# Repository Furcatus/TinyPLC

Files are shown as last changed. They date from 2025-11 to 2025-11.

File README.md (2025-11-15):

# TinyPLC

NOTE: This project is under construction. Do not expect everything to work just yet.

## What is it?
This project provides a small and easy-to-use open-source PLC (programmable logic controller) hardware / software platform intended for small automation and control tasks, built around a Raspberry Pi Pico 2W.

## Who is it for?
TinyPLC aims towards hobbyist developers and electrical engineers who want to easily automate stuff in the physical world with Python, but have been limited due to the lack of peripheral hardware connected to their microcontrollers, until now!

### Hardware features:
- 5V supply voltage
- 4 isolated digital inputs (5V to 24V, isolated external 5V supply through DC/DC converter)
- 4 relay outputs (contact: NO, up to 230V, 10A)
- SPI interface
- I²C interface
- 6 GPIOs (3,3V)
- custom 3D printable enclosure

### Software features:
- controller programmed in MicroPython
- slim PLC framework with user-defined initialization and loop function
- open-source
- possibility to use the WiFi/Bluetooth capabilities of the used Rasperry Pi Pico 2W board to build your own wireless controller

## License and Disclaimer
This project is released under the MIT license. Feel free to use it for your projects, as long as you know what you are doing when dealing with electrics/electronics. I am not liable to any harm you are causing to yourself, others or someone's property when using the provided files. Do not use TinyPLC with dangerous voltages or for safety-critical applications and follow the regulations and laws applicable in your location!

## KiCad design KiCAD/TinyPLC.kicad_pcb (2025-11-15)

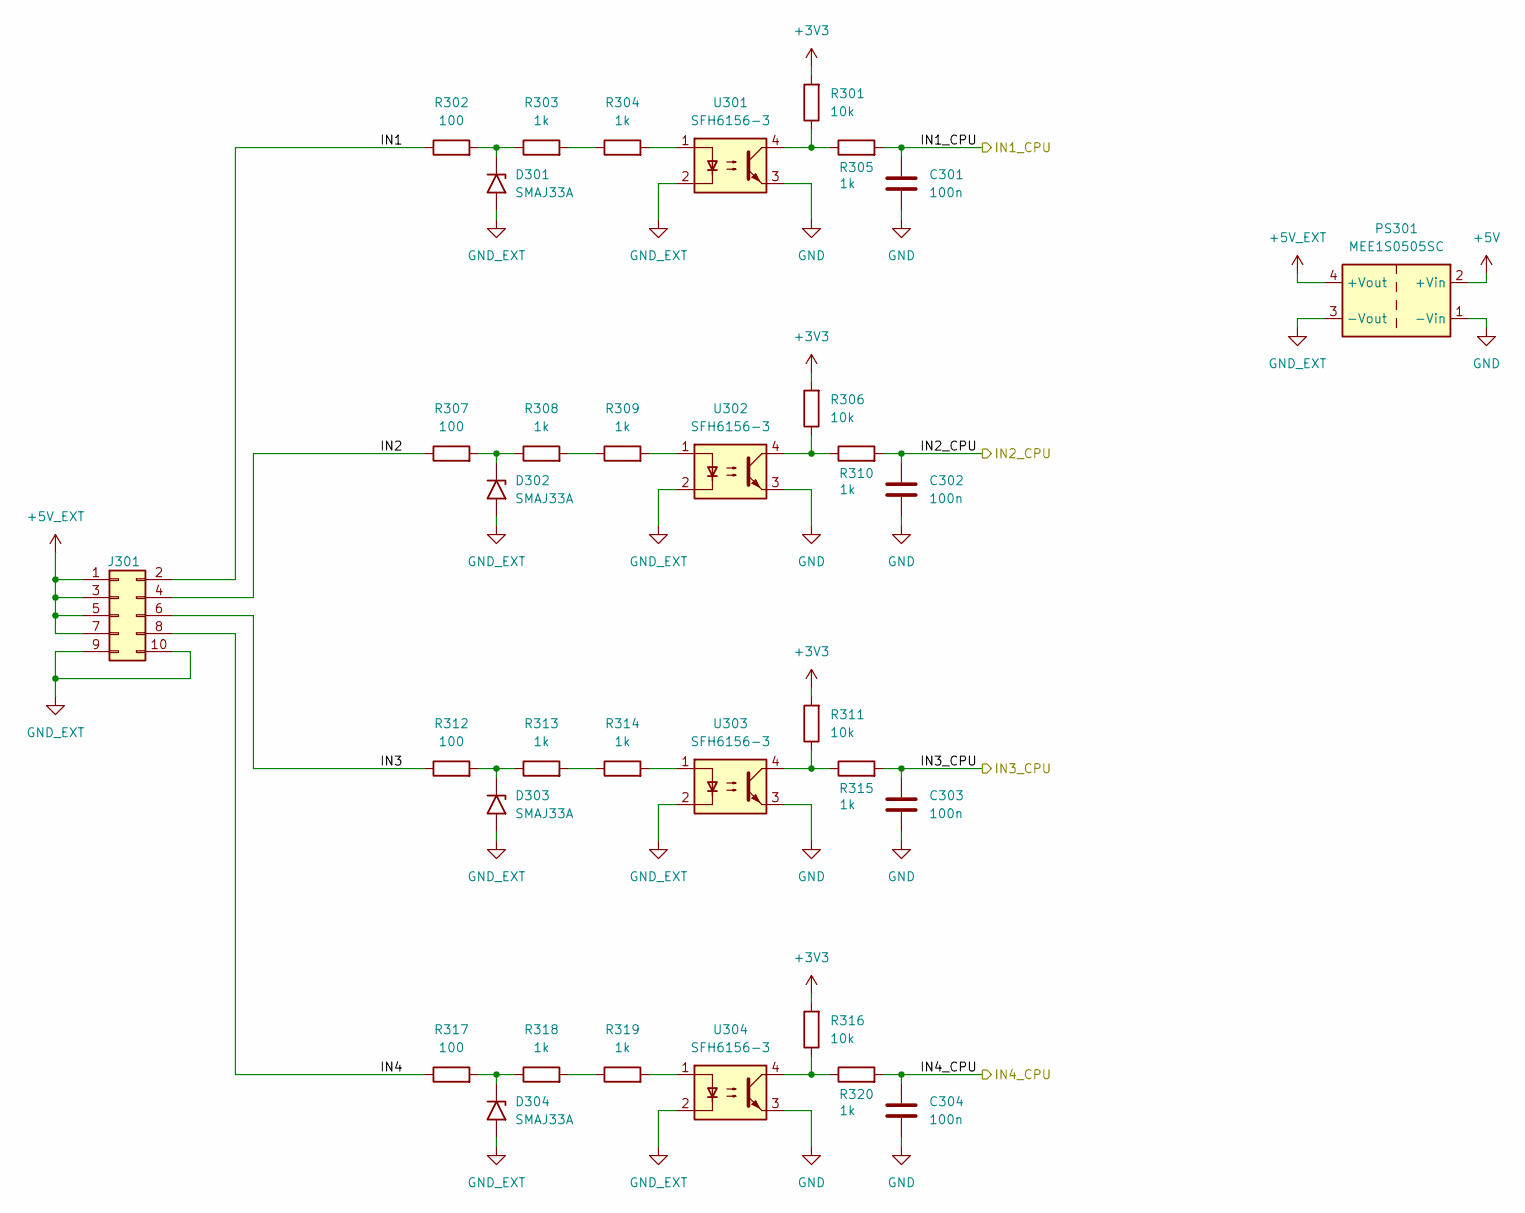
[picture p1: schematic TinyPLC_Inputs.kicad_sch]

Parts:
C301, C302, C303, C304: 100n; C_0603_1608Metric_Pad1.08x0.95mm_HandSolder
D301, D302, D303, D304: SMAJ33A; D_SMA
J301: S2L 3.50/10/180G 3.5SN OR BX; Weidmüller_S2L_2x05_3.50mm
PS301: MEE1S0505SC; Converter_DCDC_Murata_MEE1SxxxxSC_THT
R301, R306, R311, R316: 10k; R_0603_1608Metric_Pad0.98x0.95mm_HandSolder
R302, R307, R312, R317: 100; R_MiniMELF_MMA-0204
R303, R304, R308, R309, R313, R314, R318, R319: 1k; R_1206_3216Metric_Pad1.30x1.75mm_HandSolder
R305, R310, R315, R320: 1k; R_0603_1608Metric_Pad0.98x0.95mm_HandSolder
U301, U302, U303, U304: SFH6156-3; DIP-4_W7.62mm_SMDSocket_SmallPads

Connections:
+3V3: R301.2, R306.2, R311.2, R316.2; also elsewhere on the board
+5V: PS301.2 (+Vin); also elsewhere on the board
+5V_EXT: J301.1, J301.3, J301.5, J301.7, PS301.4 (+Vout)
/Controller/IN1_CPU: C301.1, R305.2; also elsewhere on the board
/Controller/IN2_CPU: C302.1, R310.2; also elsewhere on the board
/Controller/IN3_CPU: C303.1, R315.2; also elsewhere on the board
/Controller/IN4_CPU: C304.1, R320.2; also elsewhere on the board
/Inputs/IN1: J301.2, R302.1
/Inputs/IN2: J301.4, R307.1
/Inputs/IN3: J301.6, R312.1
/Inputs/IN4: J301.8, R317.1
GND: C301.2, C302.2, C303.2, C304.2, PS301.1 (-Vin), U301.3, U302.3, U303.3, U304.3; also elsewhere on the board
GND_EXT: D301.2 (A2), D302.2 (A2), D303.2 (A2), D304.2 (A2), J301.9, J301.10, PS301.3 (-Vout), U301.2, U302.2, U303.2, U304.2
unnamed: D301.1 (A1), R302.2, R303.1
unnamed: D302.1 (A1), R307.2, R308.1
unnamed: D303.1 (A1), R312.2, R313.1
unnamed: D304.1 (A1), R317.2, R318.1
unnamed: R301.1, R305.1, U301.4
unnamed: R303.2, R304.1
unnamed: R304.2, U301.1
unnamed: R306.1, R310.1, U302.4
unnamed: R308.2, R309.1
unnamed: R309.2, U302.1
unnamed: R311.1, R315.1, U303.4
unnamed: R313.2, R314.1
unnamed: R314.2, U303.1
unnamed: R316.1, R320.1, U304.4
unnamed: R318.2, R319.1
unnamed: R319.2, U304.1

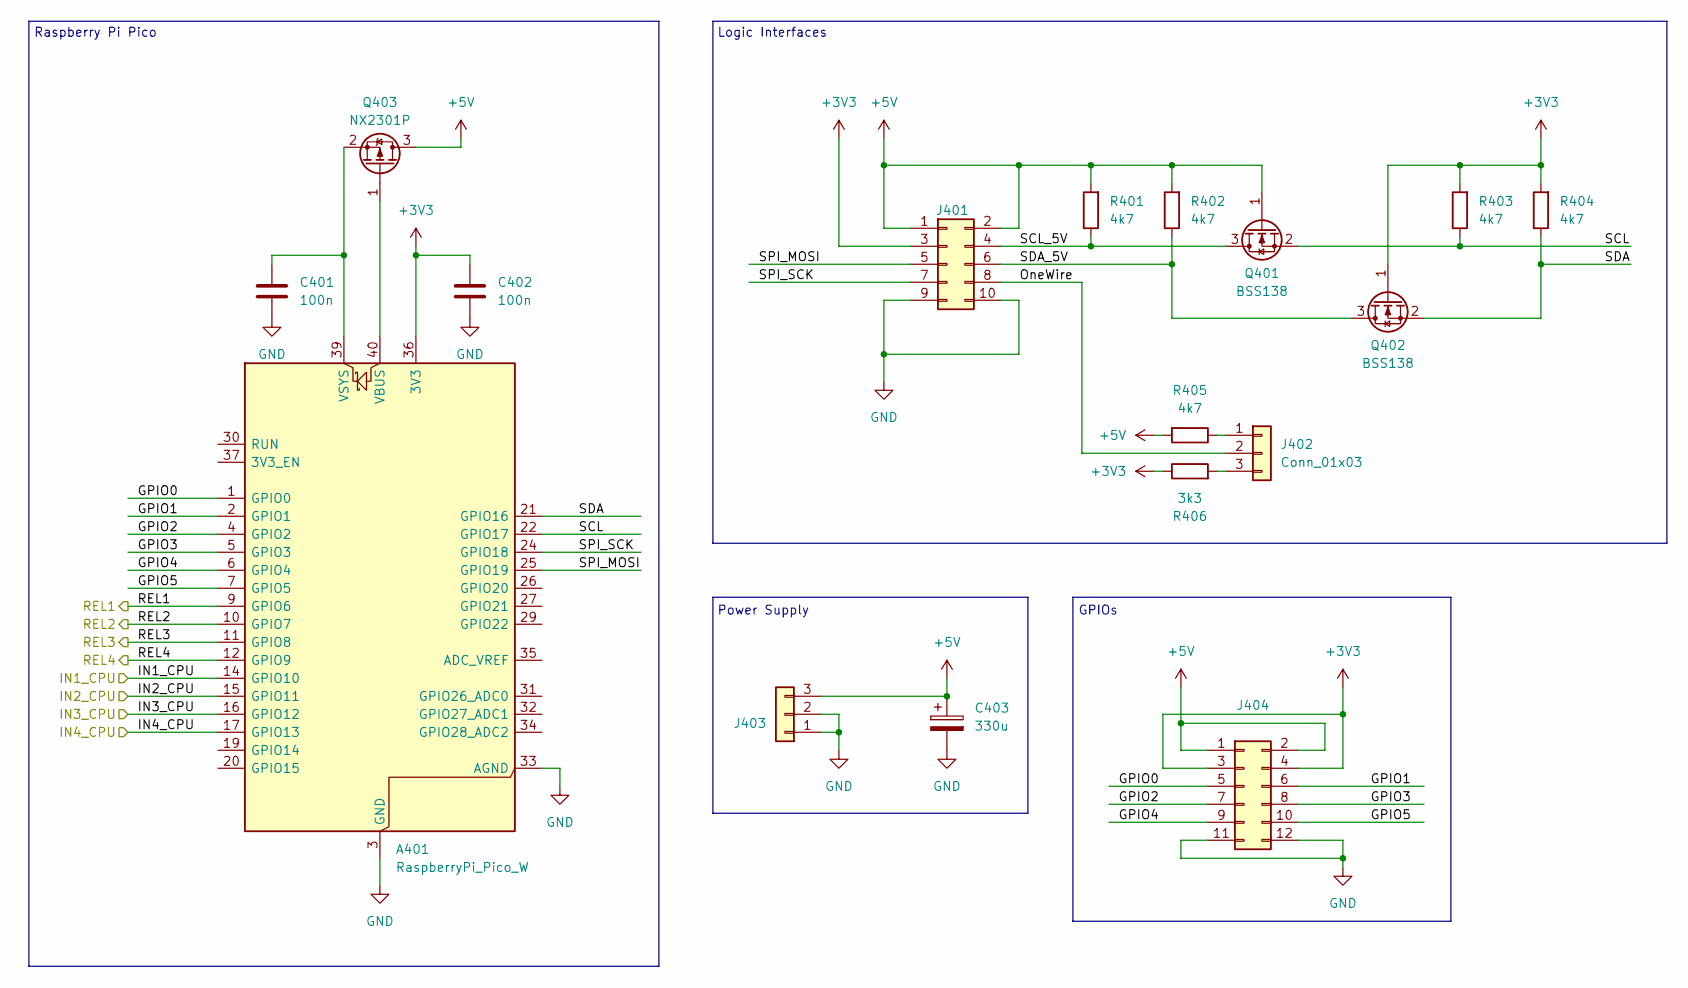
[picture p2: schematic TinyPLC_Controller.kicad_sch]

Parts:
A401: RaspberryPi_Pico_W; RaspberryPi_Pico_Common_SMD
C401, C402: 100n; C_0603_1608Metric_Pad1.08x0.95mm_HandSolder
C403: 330u; CP_Elec_6.3x5.9
J401: S2L 3.50/10/180G 3.5SN OR BX; Weidmüller_S2L_2x05_3.50mm
J402: Conn_01x03; PinHeader_1x03_P2.54mm_Vertical
J403: S2L 3.50/03/180G 3.2SN OR BX; Weidmüller_S2L_1x03_3.50mm
J404: Conn_02x06_Odd_Even; PinSocket_2x06_P2.54mm_Vertical
Q401, Q402: BSS138; SOT-23-3
Q403: NX2301P; SOT-23
R401, R402, R403, R404, R405: 4k7; R_0603_1608Metric_Pad0.98x0.95mm_HandSolder
R406: 3k3; R_0603_1608Metric_Pad0.98x0.95mm_HandSolder

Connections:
+3V3: A401.36 (3V3), C402.1, J401.3, J404.3, J404.4, Q402.1 (G), R403.2, R404.2, R406.1; also elsewhere on the board
+5V: C403.1, J401.1, J401.2, J403.3, J404.1, J404.2, Q401.1 (G), Q403.3 (D), R401.2, R402.2, R405.2; also elsewhere on the board
/Controller/GPIO0: A401.1 (GPIO0), J404.5
/Controller/GPIO1: A401.2 (GPIO1), J404.6
/Controller/GPIO2: A401.4 (GPIO2), J404.7
/Controller/GPIO3: A401.5 (GPIO3), J404.8
/Controller/GPIO4: A401.6 (GPIO4), J404.9
/Controller/GPIO5: A401.7 (GPIO5), J404.10
/Controller/IN1_CPU: A401.14 (GPIO10); also elsewhere on the board
/Controller/IN2_CPU: A401.15 (GPIO11); also elsewhere on the board
/Controller/IN3_CPU: A401.16 (GPIO12); also elsewhere on the board
/Controller/IN4_CPU: A401.17 (GPIO13); also elsewhere on the board
/Controller/OneWire: J401.8, J402.2
/Controller/REL1: A401.9 (GPIO6); also elsewhere on the board
/Controller/REL2: A401.10 (GPIO7); also elsewhere on the board
/Controller/REL3: A401.11 (GPIO8); also elsewhere on the board
/Controller/REL4: A401.12 (GPIO9); also elsewhere on the board
/Controller/SCL: A401.22 (GPIO17), Q401.2 (S), R403.1
/Controller/SCL_5V: J401.4, Q401.3 (D), R401.1
/Controller/SDA: A401.21 (GPIO16), Q402.2 (S), R404.1
/Controller/SDA_5V: J401.6, Q402.3 (D), R402.1
/Controller/SPI_MOSI: A401.25 (GPIO19), J401.5
/Controller/SPI_SCK: A401.24 (GPIO18), J401.7
GND: A401.3 (GND), A401.8 (GND), A401.13 (GND), A401.18 (GND), A401.23 (GND), A401.28 (GND), A401.33 (AGND), A401.38 (GND), C401.2, C402.2, C403.2, J401.9, J401.10, J403.1, J403.2, J404.11, J404.12; also elsewhere on the board
unnamed: A401.40 (VBUS), Q403.1 (G)
unnamed: A401.39 (VSYS), C401.1, Q403.2 (S)
unnamed: J402.1, R405.1
unnamed: J402.3, R406.2

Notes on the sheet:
Power Supply
GPIOs
Logic Interfaces
Raspberry Pi Pico

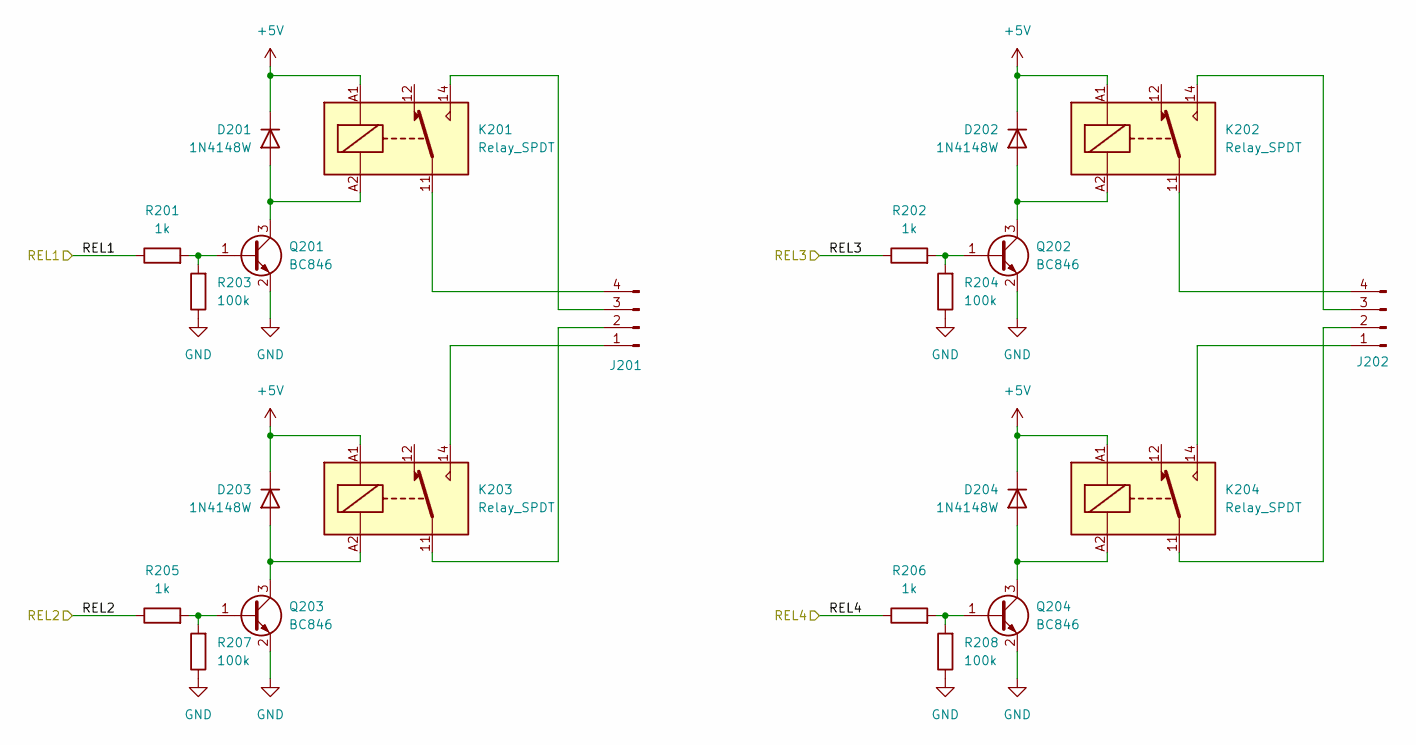
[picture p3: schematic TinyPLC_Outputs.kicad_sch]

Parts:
D201, D202, D203, D204: 1N4148W; D_SOD-123
J201, J202: Conn_01x04_Pin; PhoenixContact_MSTBVA_2,5_4-G-5,08_1x04_P5.08mm_Vertical
K201, K202, K203, K204: Relay_SPDT; Relay_SPDT_Hongfa_HF118F
Q201, Q202, Q203, Q204: BC846; SOT-23-3
R201, R202, R205, R206: 1k; R_0603_1608Metric_Pad0.98x0.95mm_HandSolder
R203, R204, R207, R208: 100k; R_0603_1608Metric_Pad0.98x0.95mm_HandSolder

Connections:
+5V: D201.1 (K), D202.1 (K), D203.1 (K), D204.1 (K), K201.A1, K202.A1, K203.A1, K204.A1; also elsewhere on the board
/Controller/REL1: R201.1; also elsewhere on the board
/Controller/REL2: R205.1; also elsewhere on the board
/Controller/REL3: R202.1; also elsewhere on the board
/Controller/REL4: R206.1; also elsewhere on the board
GND: Q201.2 (E), Q202.2 (E), Q203.2 (E), Q204.2 (E), R203.1, R204.1, R207.1, R208.1; also elsewhere on the board
unnamed: D201.2 (A), K201.A2, Q201.3 (C)
unnamed: D202.2 (A), K202.A2, Q202.3 (C)
unnamed: D203.2 (A), K203.A2, Q203.3 (C)
unnamed: D204.2 (A), K204.A2, Q204.3 (C)
unnamed: J201.1, K203.14
unnamed: J201.2, K203.11
unnamed: J201.3, K201.14
unnamed: J201.4, K201.11
unnamed: J202.1, K204.14
unnamed: J202.2, K204.11
unnamed: J202.3, K202.14
unnamed: J202.4, K202.11
unnamed: Q201.1 (B), R201.2, R203.2
unnamed: Q202.1 (B), R202.2, R204.2
unnamed: Q203.1 (B), R205.2, R207.2
unnamed: Q204.1 (B), R206.2, R208.2

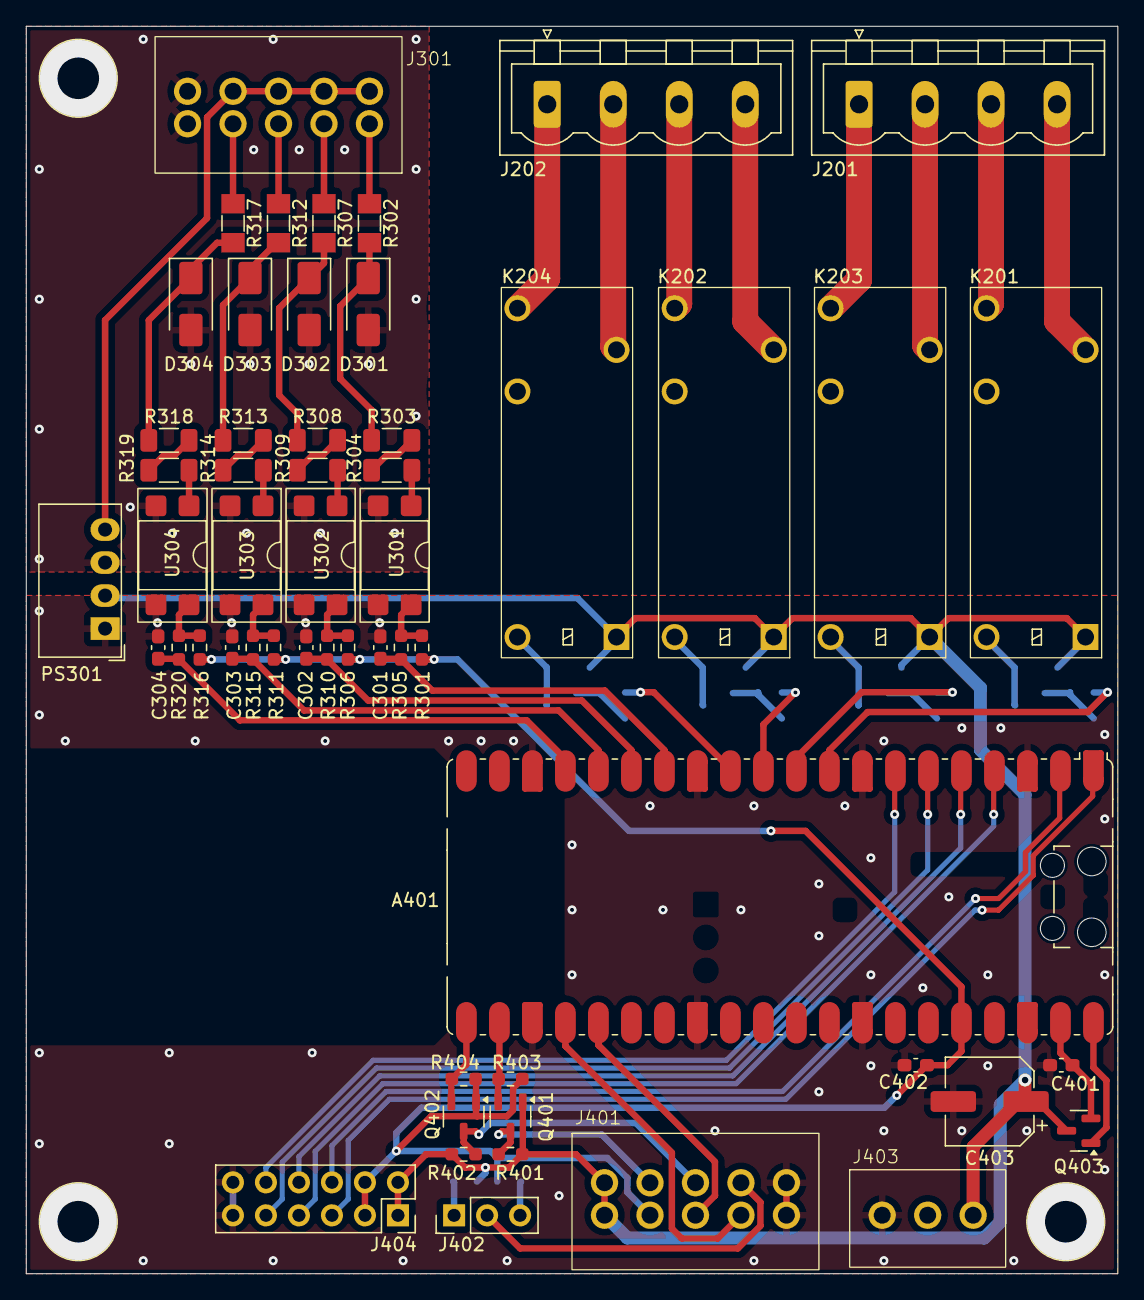
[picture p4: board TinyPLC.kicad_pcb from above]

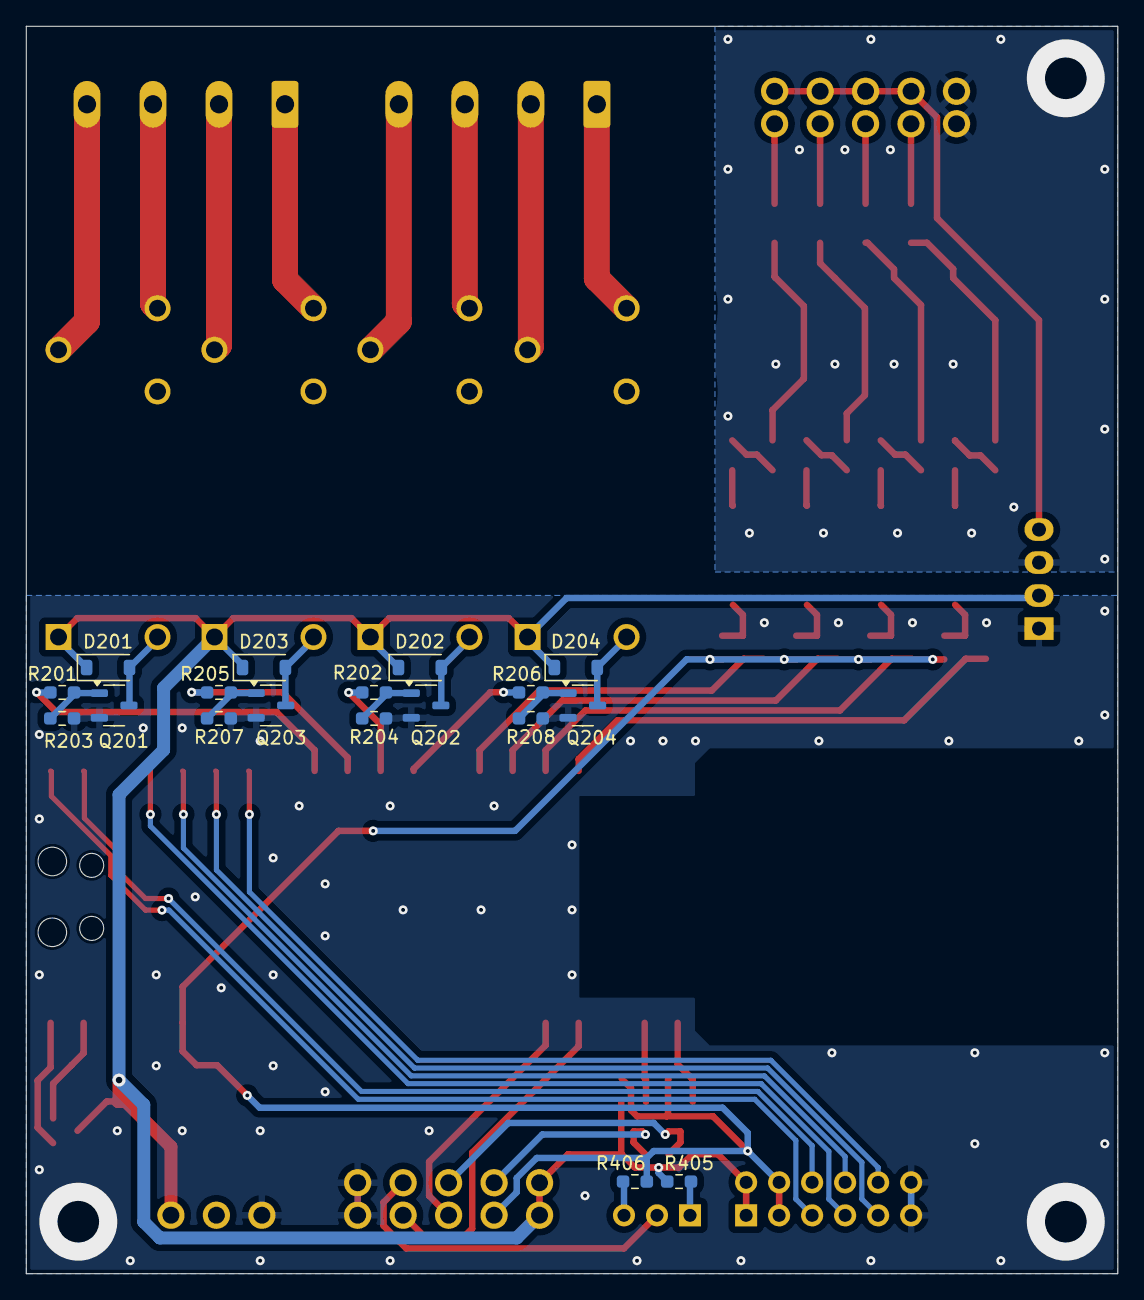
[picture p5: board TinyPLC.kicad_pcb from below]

Board: 2 copper layers, 84.0 x 96.0 mm, 73 parts (18 on the bottom side), 66 nets.

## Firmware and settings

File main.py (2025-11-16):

from tinyplc import TinyPLC
import ahtx0

humtemp = 0

def init_sensor(plc):
    global humtemp
    
    humtemp = ahtx0.AHT20(plc.serial_I2C())
    print("Init")

def loop_sensor(plc):
    global humtemp
    
    print("T: %0.2f°C" % humtemp.temperature + "\nH: %0.2f%%" % humtemp.relative_humidity)
    
def init_io(plc):
    pass

def loop_io(plc):
    plc.toggleLED()
    plc.toggleOutput(0)

if __name__ == "__main__":
    plc1 = TinyPLC(init_sensor, loop_sensor, 1000)
    plc2 = TinyPLC(init_io, loop_io, 500)
    
    plc1.start()
    plc2.start()

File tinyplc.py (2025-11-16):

# MIT License
# 
# Copyright (c) 2025 Christoph Brennig
# 
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
from machine import Pin, Signal, Timer, I2C

def clamp(x, min_x, max_x):
    return max(min(max_x, x), min_x)

class TinyPLC:
    _input_channels = [10, 11, 12, 13]
    _output_channels = [6, 7, 8, 9, "LED"]
    
    # index of board led in output list
    BOARD_LED = len(_output_channels) - 1
    
    _inputs = [0 for x in range(len(_input_channels))]
    _outputs = [0 for x in range(len(_output_channels))]

    def __init__(self, initCallback, loopCallback, loopPeriod, verbose=False):
        # initialize TinyPLC instance
        self._loopPeriod = loopPeriod
        self._loopCallback = loopCallback
        self._initCallback = initCallback
        self._verboseOutput = verbose
        
        # I/Os
        for i in range(len(self._output_channels)):
            pin = Pin(self._output_channels[i], Pin.OUT)
            self._outputs[i] = Signal(pin, invert=False)
            self._outputs[i].off()
        
        for i in range(len(self._input_channels)):
            pin = Pin(self._input_channels[i], Pin.IN)
            self._inputs[i] = Signal(pin, invert=True)
            
        # I2C
        self._i2c = I2C(id=0, freq=400000, scl=Pin(17), sda=Pin(16))
        
        if self._verboseOutput:
            print("TinyPLC initialized")
    
    def verboseOutput(enable):
        self._verboseOutput = enable
    
    def start(self):
        # setup plc loop
        self._loopTimer = Timer(period=self._loopPeriod, mode=Timer.PERIODIC, callback=self.callbackWrapper)
        
        # run user init code
        self._initCallback(self)
        
    def callbackWrapper(self, t):
        # use a wrapper to eliminate the timer reference
        try:
            self._loopCallback(self)
        except KeyboardInterrupt:
            t.deinit()
        except Exception as e:
            raise e
        
    def stop(self):
        # stop plc loop function execution
        self._loopTimer.deinit()
        
    def period(self):
        # return plc loop period
        return self._loopPeriod
    
    ### OUTPUT METHODS ###
    
    def setOutput(self, num, state):
        # take care of lousy user inputs
        state = clamp(state, 0, 1)
        num = clamp(num, 0 , len(self._outputs) - 1)
        
        # set output state
        self._outputs[num].value(state)
        
        if self._verboseOutput:
            print("Output " + str(num) + " set to " + str(state))
        
    def toggleOutput(self, num):
        # toggle output state
        # num has to be checked for boundaries, as it is used as list index
        num = clamp(num, 0 , len(self._outputs) - 1)
        self.setOutput(num, (1 - self._outputs[num].value()))
    
    def setLED(self, state):
        # set the RPi Pico onboard LED
        self.setOutput(self.BOARD_LED, state)
        
    def toggleLED(self):
        # toggle the RPi Pico onboard LED
        self.toggleOutput(self.BOARD_LED)
        
    ### INPUT METHODS ###
        
    def getInput(self, num):
        num = clamp(num, 0 , len(self._inputs) - 1)
        return self._inputs[num].value()
    
    # ToDo: edge-detection
    
    ### SERIAL INTERFACES ###
    
    def serial_I2C(self):
        return self._i2c
        

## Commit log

2025-11-15 added KiCAD files
    [TinyPLC.kicad_pcb, TinyPLC.kicad_sch, TinyPLC_Controller.kicad_sch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]
2025-11-16 - uploaded the correct files, I/Os and I2C is now working - included a sample implementation for AHT20 sensor with external library (credit and license in the file itself)
    [main.py, tinyplc.py]
